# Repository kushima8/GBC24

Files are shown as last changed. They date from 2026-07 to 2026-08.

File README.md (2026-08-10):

# GBC24
Modular Shortcut Keyboard
  


## GBC24 Build Guide
  
[はんだ付け済み版 ビルドガイド（日本語）](Documents/buildguide_pre-soldered.md)  
[接続・設定マニュアル（日本語）](Documents/GBC24_接続・設定マニュアル.pdf)
  
120px-Cc-by-nc-sa_icon svg

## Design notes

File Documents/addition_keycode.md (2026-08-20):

# GBC24 追加キーコード一覧
 
GBC24で使用できる独自キーコードの一覧です。  
RemapまたはVIAでキーに割り当ててご使用ください。
 
## ジョイスティック
 
| キーコード | 説明 |
|---|---|
| `JOY_DIGI` | ジョイスティックをデジタル4方向入力に切り替え |
| `JOY_MOUS` | ジョイスティックをマウス入力に切り替え |
| `JOY_ANLG` | ジョイスティックをアナログ軸入力【DirectInput】に切り替え |
| `JOY_SPD_UP` | マウス最大速度を上げる[^2] |
| `JOY_SPD_DN` | マウス最大速度を下げる[^2] |
| `JOY_DZ_UP` | 現在のモードのデッドゾーンを広げる（鈍くする）[^2] |
| `JOY_DZ_DN` | 現在のモードのデッドゾーンを狭める（敏感にする）[^2] |
| `JOY_DZ_RST` | 3モードすべてのデッドゾーンを既定値に戻す[^2] |
 
### デッドゾーンの調整
 
`JOY_DZ_UP` / `JOY_DZ_DN` は、**その時アクティブなモード**のデッドゾーンを1回あたり2%ずつ変更します。  
調整したいモードに `JOY_DIGI` / `JOY_MOUS` / `JOY_ANLG` で切り替えてから操作してください。  
 
| モード | 調整範囲 | 初期値 | 段階数 |
|---|---|---|---|
| デジタル | 6〜90% | 54% | 43段階 |
| マウス | 4〜90% | 24% | 44段階 |
| アナログ | 2〜90% | 12% | 45段階 |
 
デジタルモードのセンター判定しきい値は、方向判定しきい値に連動して自動調整されます。
 
## トラックボール
 
以下のキーコードは、オプションのReexトラックボールユニットを取り付けた場合にご利用いただけます。
 
### 設定の保存・リセット
 
| キーコード | 説明 |
|---|---|
| `REC_RST` | センサー設定[^1]をリセット |
| `REC_SAVE` | 現在のセンサー設定[^1]をEEPROMに保存 |
 
### CPI（カーソル速度）
 
| キーコード | 説明 |
|---|---|
| `CPI_I100` | CPIを100増加（最大3500） |
| `CPI_D100` | CPIを100減少（最小100） |
| `CPI_I1K` | CPIを1000増加（最大3500） |
| `CPI_D1K` | CPIを1000減少（最小100） |
 
### スクロール
 
| キーコード | 説明 |
|---|---|
| `SCRL_TO` | 押すたびにスクロールモードのON/OFFを切り替え |
| `SCRL_MO` | 押している間だけスクロールモード |
| `SCRL_DVI` | スクロール除数を1つ上げる（最大 D7 = 1/128、最も遅い） |
| `SCRL_DVD` | スクロール除数を1つ下げる（最小 D0 = 1/1、最も速い） |
| `SSNP_VRT` | スクロールスナップを垂直方向に固定 |
| `SSNP_HOR` | スクロールスナップを水平方向に固定 |
| `SSNP_FRE` | スクロールスナップを無効化（自由スクロール） |
 
### 自動マウスレイヤー
 
| キーコード | 説明 |
|---|---|
| `AML_TO` | 自動マウスレイヤーのON/OFFを切り替え |
| `AML_I50` | 自動マウスレイヤーのタイムアウトを50ms増加（最大1000ms） |
| `AML_D50` | 自動マウスレイヤーのタイムアウトを50ms減少（最小100ms） |

#### 動作

自動マウスレイヤーのONの状態で、トラックボールを転がすと**レイヤー3**に自動で切り替わり、操作をやめてから設定時間（初期値650ms）が経過すると元のレイヤーに戻ります。  
レイヤー3にマウスボタンやスクロールを割り当てておくことで、レイヤー切り替えキーを押さずにマウス操作ができます。  

レイヤー3では、以下のキーがトラックボールを止めた状態でもレイヤーを維持します。  
マウス操作を続けるためのキーとして扱われるためです。  

- マウスボタン（`KC_BTN1`〜`KC_BTN8`）
- `SCRL_MO`
- 修飾キー（Ctrl / Shift / Alt / GUI）

上記以外のキーを割り当てた場合、押した時点でレイヤー3が解除され、下のレイヤーのキーが入力されます（トラックボールを動かしながら押した場合はレイヤー3のキーが入力されます）。  
そのため、レイヤー3には上記のキーを割り当てることを推奨します。  

なお、キーを押した直後の約200msはトラックボールを動かしてもレイヤーが切り替わりません。  
タイピング中に手が触れてしまった際の誤動作を防ぐための仕様です。  
 
[^1]: CPI、スクロール除数、自動マウスレイヤーのON/OFF状態、および自動マウスレイヤーのタイムアウト
 
[^2]: マウス最大速度とデッドゾーンは、変更から約2秒後に自動でEEPROMへ保存されます。トラックボールの `REC_SAVE` のような保存操作は不要

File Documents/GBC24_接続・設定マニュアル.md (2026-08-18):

# GBC24 接続・設定マニュアル

ビルドガイドに、注意事項などを記載しております。
本書をお読みになる前に、必ずそちらをご確認ください。

## 1. 接続方法

GBC24は、PCやiPadなどの機器とUSB接続して使用します。
本体側の端子は USB Type-C です。

### ■ 使用するケーブル

- Type-C ⇄ Type-A
- Type-C ⇄ Type-C
  ※必ず「データ通信対応ケーブル」をご使用ください。充電専用ケーブルでは動作しません。

USB端子は精密部品です。
ケーブルを横方向に強く引っ張ると破損の原因になります。
必ずまっすぐ抜き差ししてください。

## 2. 内部のマイコンについて

GBC24の内部には、ピンク色もしくは青色の小さな基板が入っています。
これがマイコンです。
このマイコンがGBC24全体の動作を制御しPCとの接続口となっており、取り外すことができます。

内部のマイコン

※画像はオプションの液晶付きモデルです。液晶がない場合、マイコンはカバーで覆われています。

これは、

- 故障時に交換しやすくするため
- USB端子に強い力がかかった際に、本体基板へのダメージを減らすため

の設計です。

そのため、衝撃などで外れることがありますが、**故障ではありません。**

カバーにより外れにくい構造になっていますが、万が一外れてしまった場合はご連絡ください。

## 3. Remapとは？

Remapは、ブラウザ上でキーボードの設定を変更できるWebアプリです。
ソフトのインストールは不要で、Chromeブラウザのみで使用できます。

Remapでは以下の設定が可能です。

- キー配置変更
- レイヤー設定
- ジョイスティック設定
- ダイヤル操作設定

## 4. Remapの使い方

### ① サイトを開く

https://remap-keys.app/

「Start Remap for your keyboard」をクリックします。

### ② キーボードを選択

「+KEYBOARD」をクリックします。

表示された一覧から **gbc24** を選択してください。

キーボードの選択

接続が成功すると、キーボードのレイアウト画面が表示されます。

レイアウト画面

## 5. キーの動作確認

右上メニューから **テストマトリクスモード** を選択してください。

テストマトリクスモードの選択

キーを押すと水色に変わります。

すべてのキーが反応するか確認してください。

マトリクステスト

※ジョイスティック部分およびダイヤルの回転部分は、このテストモードでは反応表示されません。正常な仕様です。
ジョイスティック部分とダイヤルの回転部分については、テキストエディターなどを使用して、割り当てた入力が実際に行われるか確認してください。

各部の名称

### ■ ジョイスティックの入力モードについて

ジョイスティックの動作を確認する前に、入力モードについてご確認ください。

GBC24のジョイスティックには、次の3つの入力モードがあります。

- **デジタル4方向** … 上下左右を、割り当てたキー入力として扱います
- **マウス** … マウスカーソルの移動として扱います
- **アナログ軸【DirectInput】** … ゲームパッドのスティックのように、傾き量を含めて扱います

**初期状態では「デジタル4方向」に設定されています。**
本書の説明も、この状態を前提としています。

ジョイスティックを倒しても割り当てたキーが入力されない場合、別のモードになっている可能性があります。
その場合は、`JOY_DIGI` をいずれかのキーに割り当てて **書き込み** を行い、そのキーを押してデジタル4方向モードに切り替えてください。

モードの切り替えに使用するキーコードについては、「7. 追加キーコードについて」をご覧ください。

## 6. キー配置、ジョイスティック、ダイヤル操作の変更方法

Remap画面で以下の設定が変更できます。

- キーの役割
- ジョイスティックの方向入力と押し込み
- ダイヤルの回転動作と押し込み

### ■ 基本は「ドラッグ＆ドロップ」で変更します

Remapでは、画面下部のキー一覧からドラッグ＆ドロップする方法が最も簡単です。

**手順**

1. 画面下部に表示されているキー一覧から、設定したいキーを探します。
2. マウスでそのキーをクリックしたまま、割り当てたいキーの位置までドラッグします。
3. ドロップ（マウスを離す）すると設定が変更されます。

直感的に操作できるため、基本的にはこの方法をおすすめします。

### ■ キーをクリックして変更する方法

ドラッグ操作が難しい場合は、キーをクリックして直接変更することも可能です。

1. 変更したいキーをクリックします。
2. 表示されるキー一覧から割り当てたい機能を選択します。

### ■ 設定を保存する（重要）

キーの設定を変更しただけでは、本体には保存されていません。
必ず、右上の **「書き込み」ボタン** を押してください。

設定変更後、右上の **書き込み** を押すと GBC24に保存されます。
保存しないと変更内容は反映されません。

### ■ ダイヤル（回転）の設定方法

ダイヤル部分

ダイヤル部分には、

- 左回転
- 右回転
- 押し込み

それぞれに別の機能を設定できます。

ダイヤルの各動作をクリックし、機能を設定してください。

設定後は必ず **書き込みボタン** を押してください。

### ■ ジョイスティックの設定方法

ジョイスティック部分

ジョイスティックは、

- 上
- 下
- 左
- 右
- 押し込み

それぞれに別の機能を設定できます。

方向ごとにクリックして設定してください。

設定後は必ず **書き込みボタン** を押してください。

※ここでの設定は、デジタル4方向モードでの入力に適用されます。

### ■ 文字キーを割り当てる場合

例：Aキーを割り当てたい場合

- 対象キーをクリック
- 「Basic」カテゴリーから「A」を選択
- 設定後に **書き込み** を押す

### ■ ショートカット（同時押し）を割り当てる場合

例：Ctrl + Z を1キーで実行する場合

1. 変更したいキーをクリック

修飾キーの選択

2. Modifier（修飾キー）を選択
3. Ctrlを選択
4. Zキーを選択

Ctrl + Z の設定

5. 右上の **書き込み** を押す

これで1キーで「Ctrl + Z」が実行されます。

### ■ レイヤー機能について

GBC24には **4つのレイヤー（0th〜3rd）** があります。
レイヤーとは、キー配置を切り替える機能です。

例：

- 0thレイヤー → 通常操作
- 1stレイヤー → ショートカット
- 2ndレイヤー → ブラシ操作
- 3rdレイヤー → アプリ専用

初期状態では、0thレイヤーがデフォルトのレイヤーになっています。

現在どのレイヤーが有効かを確認したい場合は、Remapで同じ位置のキーに 0th〜3rdそれぞれ異なる文字を割り当ててください。
そのキーを押したときに入力される文字で、現在のレイヤーを判別できます。

### ■ レイヤー切替キーの設定

Remapで以下を割り当てます（Nはレイヤー番号）。

- **MO(N)** … 押している間だけNレイヤーになります
- **TG(N)** … 一度押すとNレイヤーに切り替わり、もう一度押すと元のレイヤーに戻ります
- **TO(N)** … 押すとNレイヤーに切り替わります
  もう一度押しても戻らないため、別のレイヤーに移る場合は他の `TO(N)` を押してください

レイヤー設定後も、必ず **書き込み** を押してください。

レイヤー切替キーは上記以外にもあります。
詳しくはRemapおよびQMKの公式ドキュメントをご参照ください。

## 7. 追加キーコードについて

GBC24には、通常のキー入力のほかに、本製品独自のキーコードを用意しています。
Remapで通常のキーと同じように割り当てて使用できます。

主な用途は次のとおりです。

- ジョイスティックの入力方式（デジタル4方向／マウス／アナログ軸【DirectInput】）の切り替え
- マウス最大速度の調整
- ジョイスティックのデッドゾーンの調整
- トラックボール関連の各種設定（オプションのReexトラックボールユニット装着時のみ）

一覧は下記をご覧ください。

https://github.com/kushima8/GBC24/blob/main/Documents/addition_keycode.md

以上

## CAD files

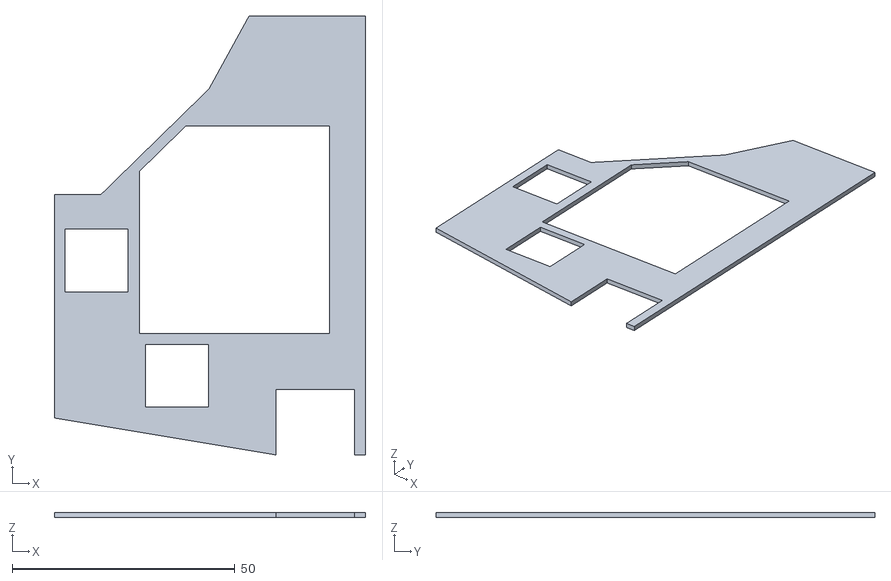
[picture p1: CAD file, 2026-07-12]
STL/gbc24_topplate_main.stl
69.8 x 98.4 x 1.20

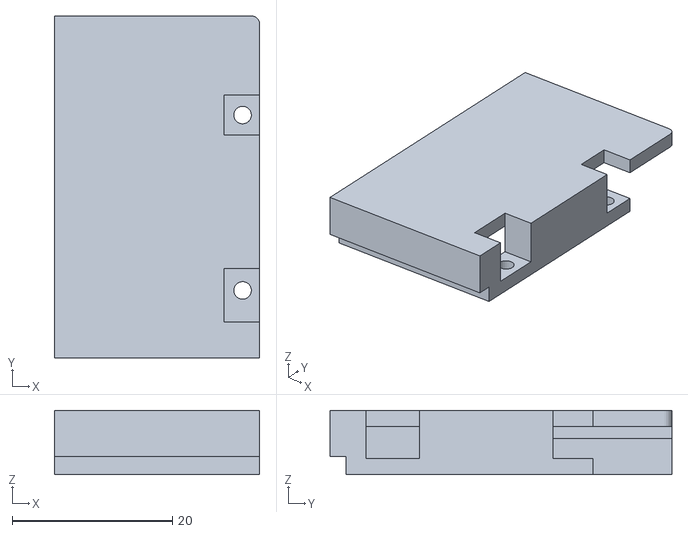
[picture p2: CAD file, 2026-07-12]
STL/gbc24_cover_2.5.stl
25.6 x 42.7 x 8.00

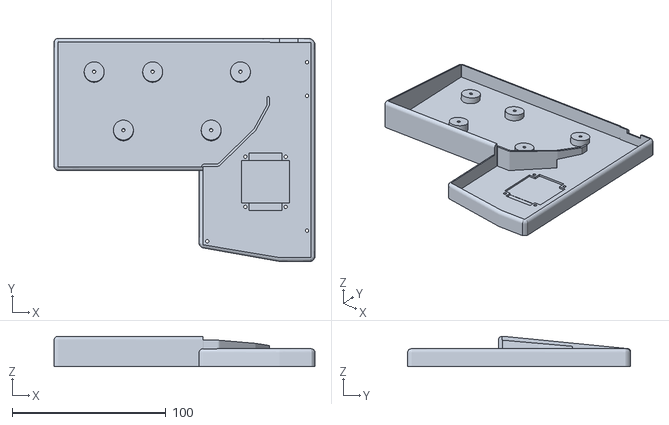
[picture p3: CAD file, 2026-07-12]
STL/gbc24_case.stl
170.0 x 145.2 x 19.9

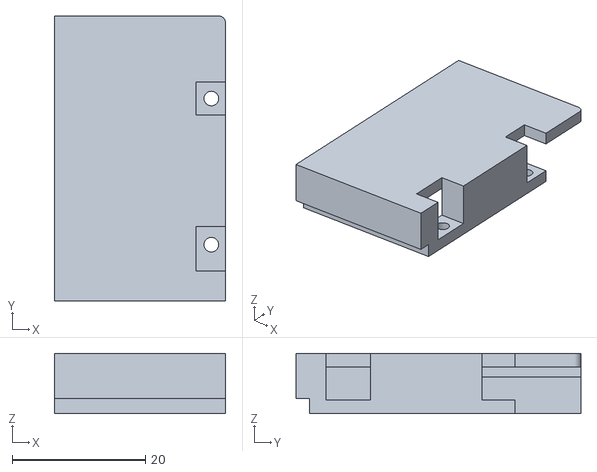
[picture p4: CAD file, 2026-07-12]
STL/gbc24_cover_3.5.stl
25.6 x 42.7 x 9.00

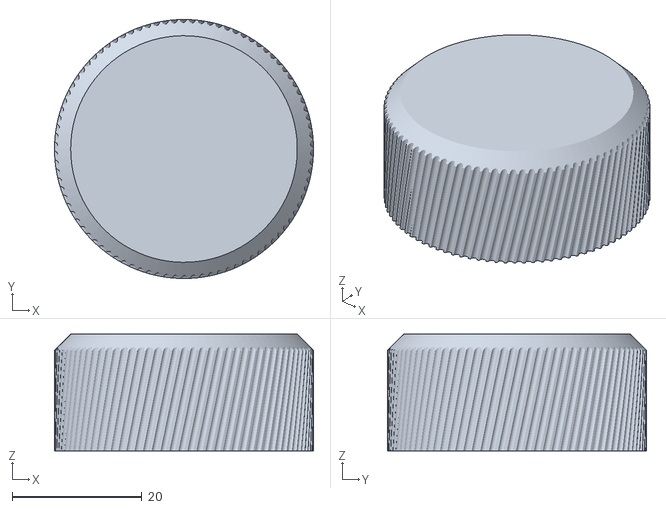
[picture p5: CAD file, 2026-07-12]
STL/gbc24_knob_40mm.stl
40.0 x 40.0 x 18.0

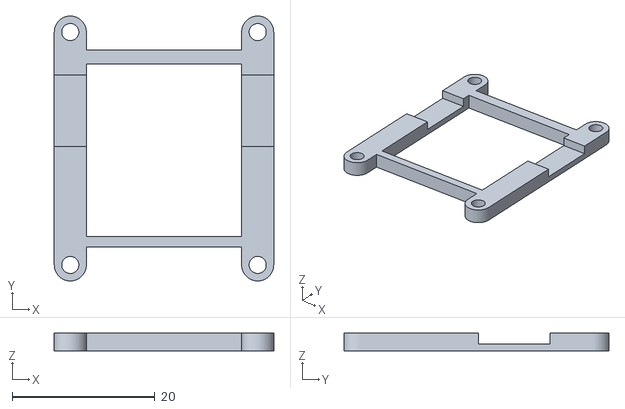
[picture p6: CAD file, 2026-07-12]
STL/gbc24_2.5_spacer.stl
30.7 x 37.1 x 2.50

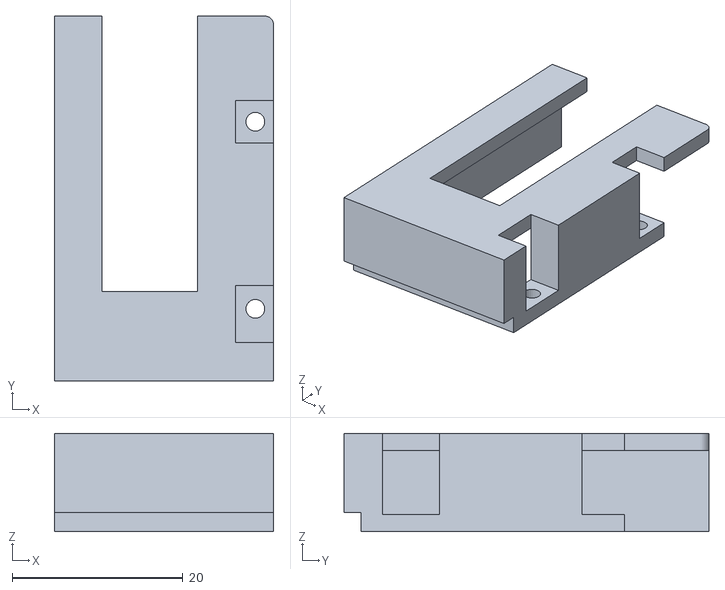
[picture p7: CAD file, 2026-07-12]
STL/gbc24_cover_oled.stl
25.6 x 42.7 x 11.5

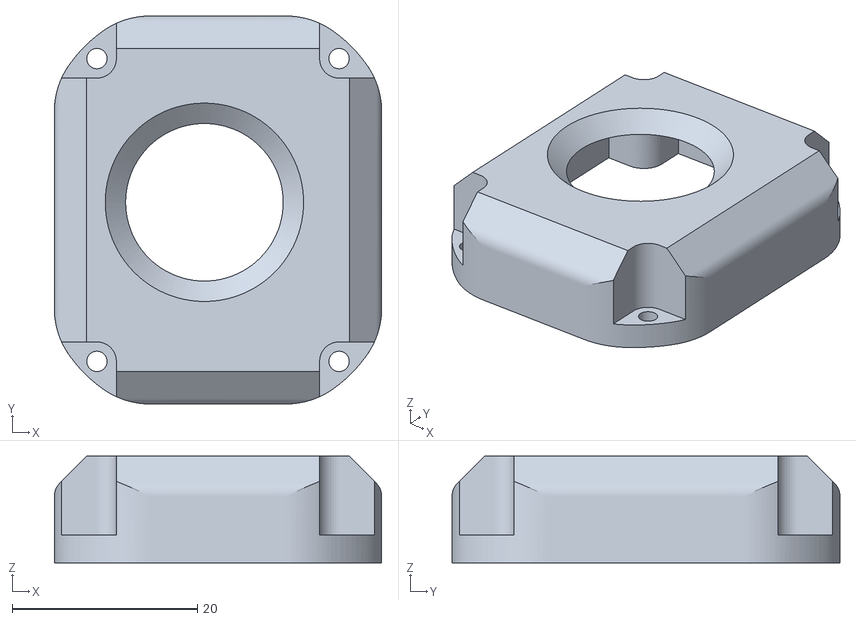
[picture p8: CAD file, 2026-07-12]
STL/gbc24_joystick_cover.stl
35.3 x 41.9 x 11.5

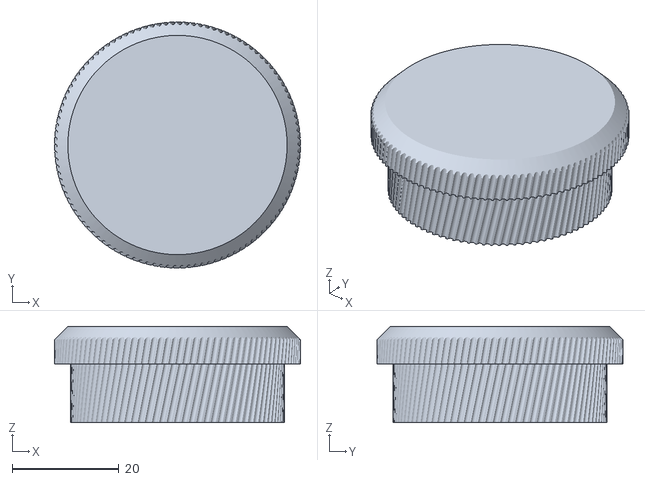
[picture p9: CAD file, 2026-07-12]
STL/gbc24_knob_46mm.stl
46.0 x 46.0 x 18.0

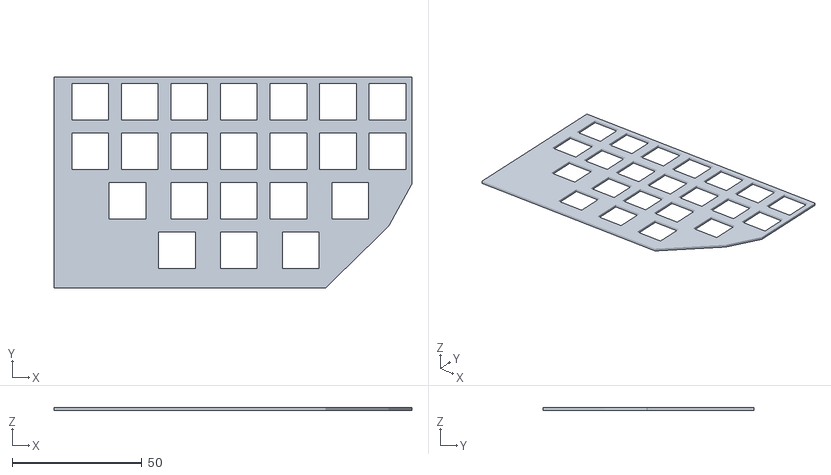
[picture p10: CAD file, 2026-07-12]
STL/gbc24_topplate_homebase.stl
137.7 x 81.1 x 1.20

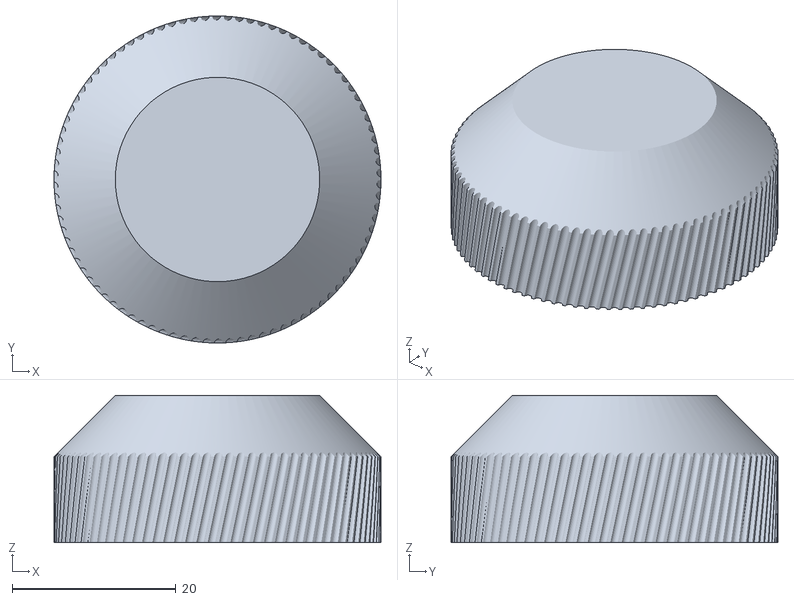
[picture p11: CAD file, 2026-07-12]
STL/gbc24_knob_25mm.stl
40.0 x 40.0 x 18.0

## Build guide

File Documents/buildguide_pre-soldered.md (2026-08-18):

# GBC24 はんだ付け済み版 ビルドガイド

## ご購入前にお読みください

本製品をご購入いただいた時点で、下記「譲渡・再販について」の内容にご同意いただいたものとみなします。

### 譲渡・再販について

BOOTHや遊舎工房など、作者本人が販売または委託している場所以外で購入された場合、同梱品の不足や不良品への対応など、各種サポートをいたしかねます。  
そのため、以下のとおりお願いしております。

1. 本製品（完成品・未完成品・付属部品を問わず）を、ネットオークション、フリマサービス、その他の方法により第三者へ有償で譲渡することを禁止します。
2. 本項に反する行為を確認した場合、以後の販売をお断りする場合があります。

## はじめに

GBC24 完成イメージ

このたびはご購入いただきありがとうございます。  
本製品は、本体がある程度組み立て済みのキットです。  

作成にあたり不明点や疑問点などがありましたら、作者の[Twitterアカウント](https://twitter.com/kushima8)までリプライやDMでご連絡ください。  
Twitter以外でご連絡をいただいても、対応いたしかねます。  
FF外からのリプライは通知をオフにしており、気づかない場合がございます。あらかじめご了承ください。  
また、Discordなどのコミュニティで、作者以外の方に質問して解決を図ることは推奨しておりません。  

GBC24は絵を描く方向けに開発したショートカットキーボードです。  

写真は作成見本であり、商品内容と同一ではありません。  
また、仕様は予告なく変更されることがあります。  

### 開発協力

本製品の開発にあたり、[すこやかむいむい](https://x.com/sukoyakamuimui)さんにご協力いただきました。ありがとうございます。

むいむいさんご本人から、紹介イラストもご提供いただきました。

<!-- 画像パスを差し替えてください。GitHubにアップロードしたURL、
     またはリポジトリ内の相対パスを指定します。 -->
すこやかむいむいさんによるGBC24紹介イラスト（イラスト：すこやかむいむいさん）

---

ファームウェアに[qmk_firmware](https://github.com/qmk/qmk_firmware)を採用しています。  
QMKにGBC24のコードはマージされていませんので、この[ブランチ](https://github.com/kushima8/qmk_firmware/tree/reex)を使用してください。  
動作確認のためのコンパイル済みファームウェアとして、[HEXファイル](https://github.com/kushima8/GBC24/tree/main/HEX)と[UF2ファイル](https://github.com/kushima8/GBC24/tree/main/UF2)を用意しています。  

購入時にマイコン(Pro MicroかKB2040)が付属している場合のみ、あらかじめファームウェアを書き込んであります。  
他のファームウェアを書き込む場合などは、下記サイトを参考にしてください。  
[（初心者編）自作キーボードにファームウェアを書き込む](https://salicylic-acid3.hatenablog.com/entry/qmk-toolbox)  

GUIから簡単にキー割り当てを変更できる[VIA](https://caniusevia.com/)と[Remap](https://remap-keys.app/)に対応しております。  
ロータリーエンコーダの回転割り当ても含めて設定できますので、ご活用ください。  
VIAとRemapについては、下記のサイトを参考にしてください。  
[（初心者編）VIAを使ってキーマップを書き換えよう](https://salicylic-acid3.hatenablog.com/entry/via-manual)  
[（初心者編）Remapを使ってキーマップを書き換えよう](https://salicylic-acid3.hatenablog.com/entry/remap-manual)  

以下の部品リストを参考に、欠品がないか確認をお願いします。  
欠品や不良品などがありましたら、確認したのちに対応いたします。  
ただし、海外など発送が難しい場合は、こちらの指定する方法での一部返金などで対応します。  
あらかじめご了承ください。  

## 部品

### キットに付属しているもの

| 名称 | 数量 | 備考 |
|---|:----:|---|
| PCB（制御部） | 1枚 | 細長型 |
| PCB（キー部） | 1枚 | ホームベース型 |
| PCB（ジョイスティック部） | 1枚 |  |
| トッププレート | 2枚 | 制御部用とキー部用 |
| 3Dプリント製ケース | 1個 |  |
| 3Dプリント製ジョイスティックカバー | 1個 |  |
| 3Dプリント製マイコンカバー | 1個 |  |
| M2 3.5mmスペーサー（ARB-2003.5E） | 4個 | 丸型両メネジ |
| M2 6mmスペーサー（ARB-2006E） | 3個 | 丸型両メネジ |
| M2 7.5mmスペーサー（ARB-2007.5E） | 6個 | 丸型両メネジ |
| M2 4mmネジ | 11本 |  |
| M2 6mmネジ | 9本 |  |
| M2 8mmネジ | 6本 |  |
| サムスティックキャップ | 1個 |  |
| ロータリーエンコーダ用ノブ | 3個 | 円柱型とすり鉢型と段付き型 |
| XHコネクタ付きケーブル 8P | 1個 |  |
| コンスルーピンヘッダ（6mm 4PIN） | 2個 |  |
| Pro Micro | 1個 | ※１ |
| コンスルーピンヘッダ（2.5mm 12PIN） | 2個 |  |
| ゴム足 | 4個 |  |

※組み立て済みの場合は、上記部品が組み込まれたものが本体扱いで付属しております。

### 別途購入が必要なもの

以下の部品は別途購入してください。

| 名称 | 数量 | 備考 |
|---|:----:|---|
| キースイッチ（Kailh Choc V1/V2系統） | 24個 | ※２ |
| キーキャップ（Kailh Choc V1/V2系統） | 24個 | ※２ |
| パームレスト | 1個 | 小型（セパレート型）なものを推奨 ※２ |

### オプション

以下の部品はオプション品です。
液晶を追加したい場合など、必要に応じて別途購入し、はんだ付けを実施してください。

| 名称 | 数量 | 備考 |
|---|:----:|---|
| OLEDモジュール | 1個 |  |
| OLED用ピンソケット | 1個 |  |
| KB2040 | 1個 | ※1 |
| コンスルーピンヘッダ（3.5mm 12PIN） | 2個 |  |
| Reexトラックボールユニット | 1個 |  |

> **※1 対応するPro Micro / KB2040について**
>
> 動作確認しているPro MicroとKB2040（RP2040 Kee Boar Driver / Adafruit）は以下のとおりです。
> 下記以外のPro Microを使用する場合は動作しないことがあります。その場合はご自身で調整してください。
>
> - [Pro Micro（単体）黒基板/青基板](https://shop.yushakobo.jp/products/pro-micro?variant=42225070768359)
> - [Pro Micro ATmega32U4-MU 5V/16MHz/USB-C（互換品/青）](https://shop.talpkeyboard.com/products/promicro-atmega32u4mu-5v16mhz-usb-c)
> - [RP2040 Kee Boar Driver](https://akizukidenshi.com/catalog/g/g117312/)

> **※2 おすすめの部品について**
>
> 別途購入が必要な部品について、作者が動作・使用感を確認しているものを紹介します。
> あくまで一例ですので、対応する規格のものであればお好みの製品をお使いいただけます。
>
> **キースイッチ（Kailh Choc V2）**
>
> どちらも静音リングを内蔵したロープロファイルスイッチで、打鍵音が控えめです。
> 5個入りのため、24個必要な場合は5袋（25個）ご購入ください。
>
> - [Kailh Deep Sea Silent MINI Islet（サイレントリニア / 45g）](https://shop.talpkeyboard.com/products/kailh-deep-sea-silent-mini-chocv2-islet) …… 引っかかりのない軽い押し心地が好みの方向け
> - [Kailh Deep Sea Silent MINI Whale（サイレントタクタイル / 45g）](https://shop.talpkeyboard.com/products/kailh-deep-sea-silent-mini-chocv2-whale) …… 押した感触をはっきり感じたい方向け
>
> **キーキャップ（Tai-Hao THT / MX軸用）**
>
> 18.1mm角のロープロファイルキーキャップです。無刻印で、1個単位から購入できます。
> レイアウトに合わせて1Uと1.5Uを組み合わせてください。
>
> - [THT ロープロファイル キーキャップ 1U（ホワイト）](https://shop.talpkeyboard.com/products/tht-mx-1u-white-bulk)
> - [THT ロープロファイル キーキャップ 1.5U（ホワイト）](https://shop.talpkeyboard.com/products/tht-mx-1-5u-white)
>
> 上記キーキャップはMX軸用のため、MX互換ステムを持つ**Choc V2にのみ対応**します。
> Choc V1のスイッチを使用する場合は、Choc V1専用のキーキャップをご用意ください。
>
> **パームレスト**
>
> - [サンワサプライ ハニカムリストレスト Sサイズ（TOK-HONEY1BK）](https://www.sanwa.co.jp/product/syohin?code=TOK-HONEY1BK)
>
> W145×D75×H21mmと小型で、GBC24のサイズによく合います。TPE素材のため水洗いが可能です。

### 3Dプリント製部品のデータについて

ケース、ジョイスティックカバー、マイコンカバー、ロータリーエンコーダ用ノブなどの3Dモデルデータ（STL）を公開しています。

[STLデータ（GitHub）](https://github.com/kushima8/GBC24/tree/main/STL)

ライセンスは **[CC BY-NC-SA 4.0（表示-非営利-継承 4.0 国際）](https://github.com/kushima8/GBC24/blob/main/LICENSE)** です。
以下の条件を守っていただければ、ご自由に出力・改変してご利用いただけます。

- **表示（BY）** …… 作者のクレジットと、ライセンスへのリンクを明記してください。改変した場合は、その旨も記載してください。
- **非営利（NC）** …… 営利目的での利用はできません。出力品の販売もこれに含まれます。
- **継承（SA）** …… 改変したデータを公開する場合は、同じCC BY-NC-SA 4.0（または互換ライセンス）で公開してください。

破損時の再出力や、お好みに合わせたカスタマイズなどにご活用ください。

## 組み立て

### 1. トッププレートにキースイッチを取り付け

- 2つあるトッププレートそれぞれの穴に、ピンが下になるようにキースイッチを取り付けてください。
- キースイッチがはまりにくい場合は、ヤスリなどを使用してトッププレートの穴を調整してください。
- キースイッチ取り付け後、各キースイッチにキーキャップを取り付けてください。

トッププレートにキースイッチを取り付けた状態

### 2. 本体にトッププレートとキースイッチを取り付け

- キースイッチを取り付けたトッププレートを、本体に差し込んでください。
- この際、スイッチのピンが曲がらないよう十分ご注意ください。
- すでにロータリーエンコーダへノブが取り付けてある場合は、一度外してください。
- 細長型のトッププレートは、マイコン取り付け部方向（接続端子部の方向）に溝があります。そこにトッププレートをはめてから本体に取り付けてください。

本体への取り付け1
本体への取り付け2
本体への取り付け3

- 取り付け後、[Remap](https://remap-keys.app/)などを使用して、すべてのキースイッチが正しく認識されているか入力確認を行ってください。

### 3. ロータリーエンコーダへノブの取り付け

- ジョイスティック右下にあるロータリーエンコーダへノブを取り付けます。
- 円柱型とすり鉢型と段付き型の３種類を同梱しておりますので、お好きな方を軸とダイヤルの穴の形を合わせて取り付けてください。
- 取り付け後、[Remap](https://remap-keys.app/)などを使用して、ロータリーエンコーダとジョイスティックが正しく認識されているか入力確認を行ってください。

ノブを取り付けた状態

組み立ての手順は、以上です。

## 接続・設定について

組み立て後の接続方法やキー割り当ての設定については、下記をご覧ください。

[接続・設定マニュアル（日本語）](Documents/GBC24_接続・設定マニュアル.md)

### 追加キーコード
 
GBC24では、ジョイスティックのモード切替やマウス速度の調整など、独自のキーコードを用意しています。  
トラックボール関連のキーコードは、オプションのReexトラックボールユニットを取り付けた場合にご利用いただけます。
 
[追加キーコード一覧](Documents/addition_keycode.md)

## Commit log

2026-07-12 add stl
    [gbc24_2.5_spacer.stl, gbc24_case.stl, gbc24_cover_2.5.stl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]
2026-11-04 Create GBC24 接続・設定マニュアル（トラックボールユニット装着版）.md
2026-11-04 Update GBC24 接続・設定マニュアル（トラックボールユニット装着版）.md
2026-11-04 Rename GBC24 接続・設定マニュアル（トラックボールユニット装着版）.md to GBC24_接続・設定マニュアル（トラックボールユニット装着版）.md
